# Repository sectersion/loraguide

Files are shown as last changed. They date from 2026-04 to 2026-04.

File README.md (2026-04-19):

# loraguide

Hello! In this guide, you will create a custom Meshtastic-enabled LORA board with a microcontroller, antenna, radio chip, and other things.

## First things first

To start your project, we need to download KiCad. KiCad is an open-source software for designing circuit boards, or PCBs. We can use the terms interchangably.

Go to https://www.kicad.org/download/ and install the version for your OS. After that finishes, create a new project. Name it anything you want, but I will name mine Loraguide.

After that finishes, you should be on a screen that looks like this: 



# The Schematic

The first step to designing a circuit board is the schematic. A schematic is essentially a wiring diagram, to show which components connect to what. That means it is very important that we follow a few design rules when creating our schematic:

 - Power symbols always point up
 - Ground symbols always point down
 - Net labels can be used instead of wires

First, click **Schematic Editor** on the main project page. Hit the **A** key to open the symbol chooser. Search "esp32-s3" and select the **ESP32-S3-WROOM-1**.



Place it in the middle. Next, search for the **SX1262** radio chip and place it to the left of the ESP32.

## Power system

### Organization
To keep things clean, use **Power Symbols** instead of drawing wires everywhere. Hit **P**, type +3V3, and place it on the 3V3 pin of the ESP32. Do the same for GND.

### Power input
Search for "USB_C_Receptacle_USB2.0_14P". 

Connect the GND pins to a GND power symbol. **Note on the SHIELD pins:** Do not connect these directly to GND. This can feed RF noise back into your host computer. For this project, leave the shield pins isolated or connected to a separate chassis pad if available.

Connect **VBUS** to a **+5V** power symbol. Place two **5.1k ohm** resistors (R_Small) on the **CC1** and **CC2** pins and connect the other ends to GND. This ensures your USB-C charger provides the correct 5V.



## SX1262 Power & RF

### Power Decoupling
Chips draw sudden bursts of current. Decoupling capacitors (100nF and 10µF) act as local water tanks, sitting right next to the chip to handle these bursts.

Connect **VDD_IN** to **+3V3** and place one **100nF** and one **10µF** capacitor between that line and GND.

### The DCC_SW Inductor
The SX1262 has an internal DC-DC converter that requires a **15µH inductor** on the **DCC_SW** pin. This inductor needs special care; it is a switching component right next to the radio. On the PCB, it must be placed as close as possible to the pin.

### RF Output Matching
Simply running a wire to the antenna is inefficient and can be illegal because it emits harmonics. You need a **matching network** (filtering) on the RF output. This usually involves a series inductor and capacitors to GND between the **RFO** pin and the antenna connector.

| Pin | What to do: |
|---|---|
| VDD_IN | Decouple with 100nF and 10µF |
| VBAT | Draw a direct wire to VDD_IN |
| VBAT_IO | Decouple with one 100nF capacitor |
| VREG | Decouple with one 100nF capacitor |
| DCC_SW | Connect 15µH inductor |
| VR_PA | 100nF capacitor to GND (DO NOT connect to 3.3V) |
| GND | Connect directly to GND |

### 5V to 3.3V conversion
Use an **AMS1117-3.3** LDO regulator to convert the 5V from USB to the 3.3V our chips need.

| Pin | Connection |
|-----|---|
| VIN | +5V from VBUS + 10µF cap to GND |
| VOUT | +3V3 + 10µF cap to GND |
| GND | GND |

## USB Data, Buttons, and SPI

### USB Data Lines
Connect the **D+** and **D-** pins of the USB connector to the **USB Data + and -** pins on the ESP32. Use **Net Labels (L)** to keep the wires from crossing.

### Boot and Reset Buttons
Both the **EN** (Reset) and **GPIO0** (Boot) pins need a **10kΩ pull-up resistor** to 3.3V. Connect push buttons that pull these pins to GND when pressed.

### SPI & Control Wiring
| Signal | ESP32 Pin | SX1262 Pin |
|---|---|---|
| SCK | GPIO5 | SCK |
| MOSI | GPIO6 | MOSI |
| MISO | GPIO7 | MISO |
| NSS | GPIO8 | NSS |
| RESET  | GPIO3 | RESET |
| BUSY | GPIO4 | BUSY |
| DIO1 | GPIO9 | DIO1 |

# PCB Section

## Footprint Assignment
In **Tools > Assign Footprints**, assign the physical shapes. For resistors and capacitors, **R_0402** or **C_0402** are standard for these boards.

## Placement
1. **ESP32:** Place at the top. Ensure the antenna "keep-out" area is outside the board edge.
2. **SX1262 & U.FL Connector:** Place these very close together.
3. **DCC_SW Inductor:** Place this right against the radio chip pin.
4. **Decoupling Caps:** Place them right next to their respective power pins.

## Routing Order
Sensitive signals must be routed first so they have the cleanest, most direct paths.

1. **RF Trace First:** Shortest path from chip to antenna. Use 45-degree angles.
2. **USB Data Lines:** Route D+ and D- as a pair, keeping them similar in length.
3. **SPI & Control Signals:** Connect the communication lines.
4. **Power Traces:** 3.3V and 5V. Use wider traces (0.5mm) for these.
5. **GND:** Handled by the copper pour.

## Ground Plane and Stitching
Add a **Filled Zone (Z)** for GND on both the top (**F.Cu**) and bottom (**B.Cu**) layers. 

To prevent "floating" ground islands and interference, add **stitching vias**. These are small holes that connect the top and bottom ground planes. Place them around the perimeter of the board and near the RF trace.

## Final Steps
Run the **DRC (Design Rule Check)** to find errors. Export your **Gerbers** and **Drill Files**, zip them up, and upload to a manufacturer like JLCPCB.

You have designed a grounded and RF-safe LoRa board.

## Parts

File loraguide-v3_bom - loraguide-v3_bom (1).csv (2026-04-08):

Designator | Footprint | Quantity | Value | LCSC Part #
C1, C3, C4, C5 | 402 | 4 | 100nF | C60474
C2, C6, C7 | 402 | 3 | 10uF | C315248
J1 | USB_C_Receptacle_GCT_USB4085 | 1 | USB_C_Receptacle_USB2.0_14P | C7095263
J2 | U.FL_Hirose_U.FL-R-SMT-1_Vertical | 1 | Conn_Coaxial | C434808
L1 | 603 | 1 | 15uH | C486329
R1, R2 | 402 | 2 | 5.1k | C105872
R3, R4 | 402 | 2 | 10k | C60490
SW1 | SW_SPST_B3U-1000P | 1 | RST | C231329
SW2 | SW_SPST_B3U-1000P | 1 | BOOT | C231329
U1 | ESP32-S3-WROOM-1 | 1 | ESP32-S3-WROOM-1 | C2913197
U2 | QFN-24-1EP_4x4mm_P0.5mm_EP2.6x2.6mm | 1 | SX1262IMLTRT | C191341
U3 | SOT-223-3_TabPin2 | 1 | AMS1117-3.3 | C6186
U4 | Bosch_LGA-8_2.5x2.5mm_P0.65mm_ClockwisePinNumbering | 1 | BME280 | C92489

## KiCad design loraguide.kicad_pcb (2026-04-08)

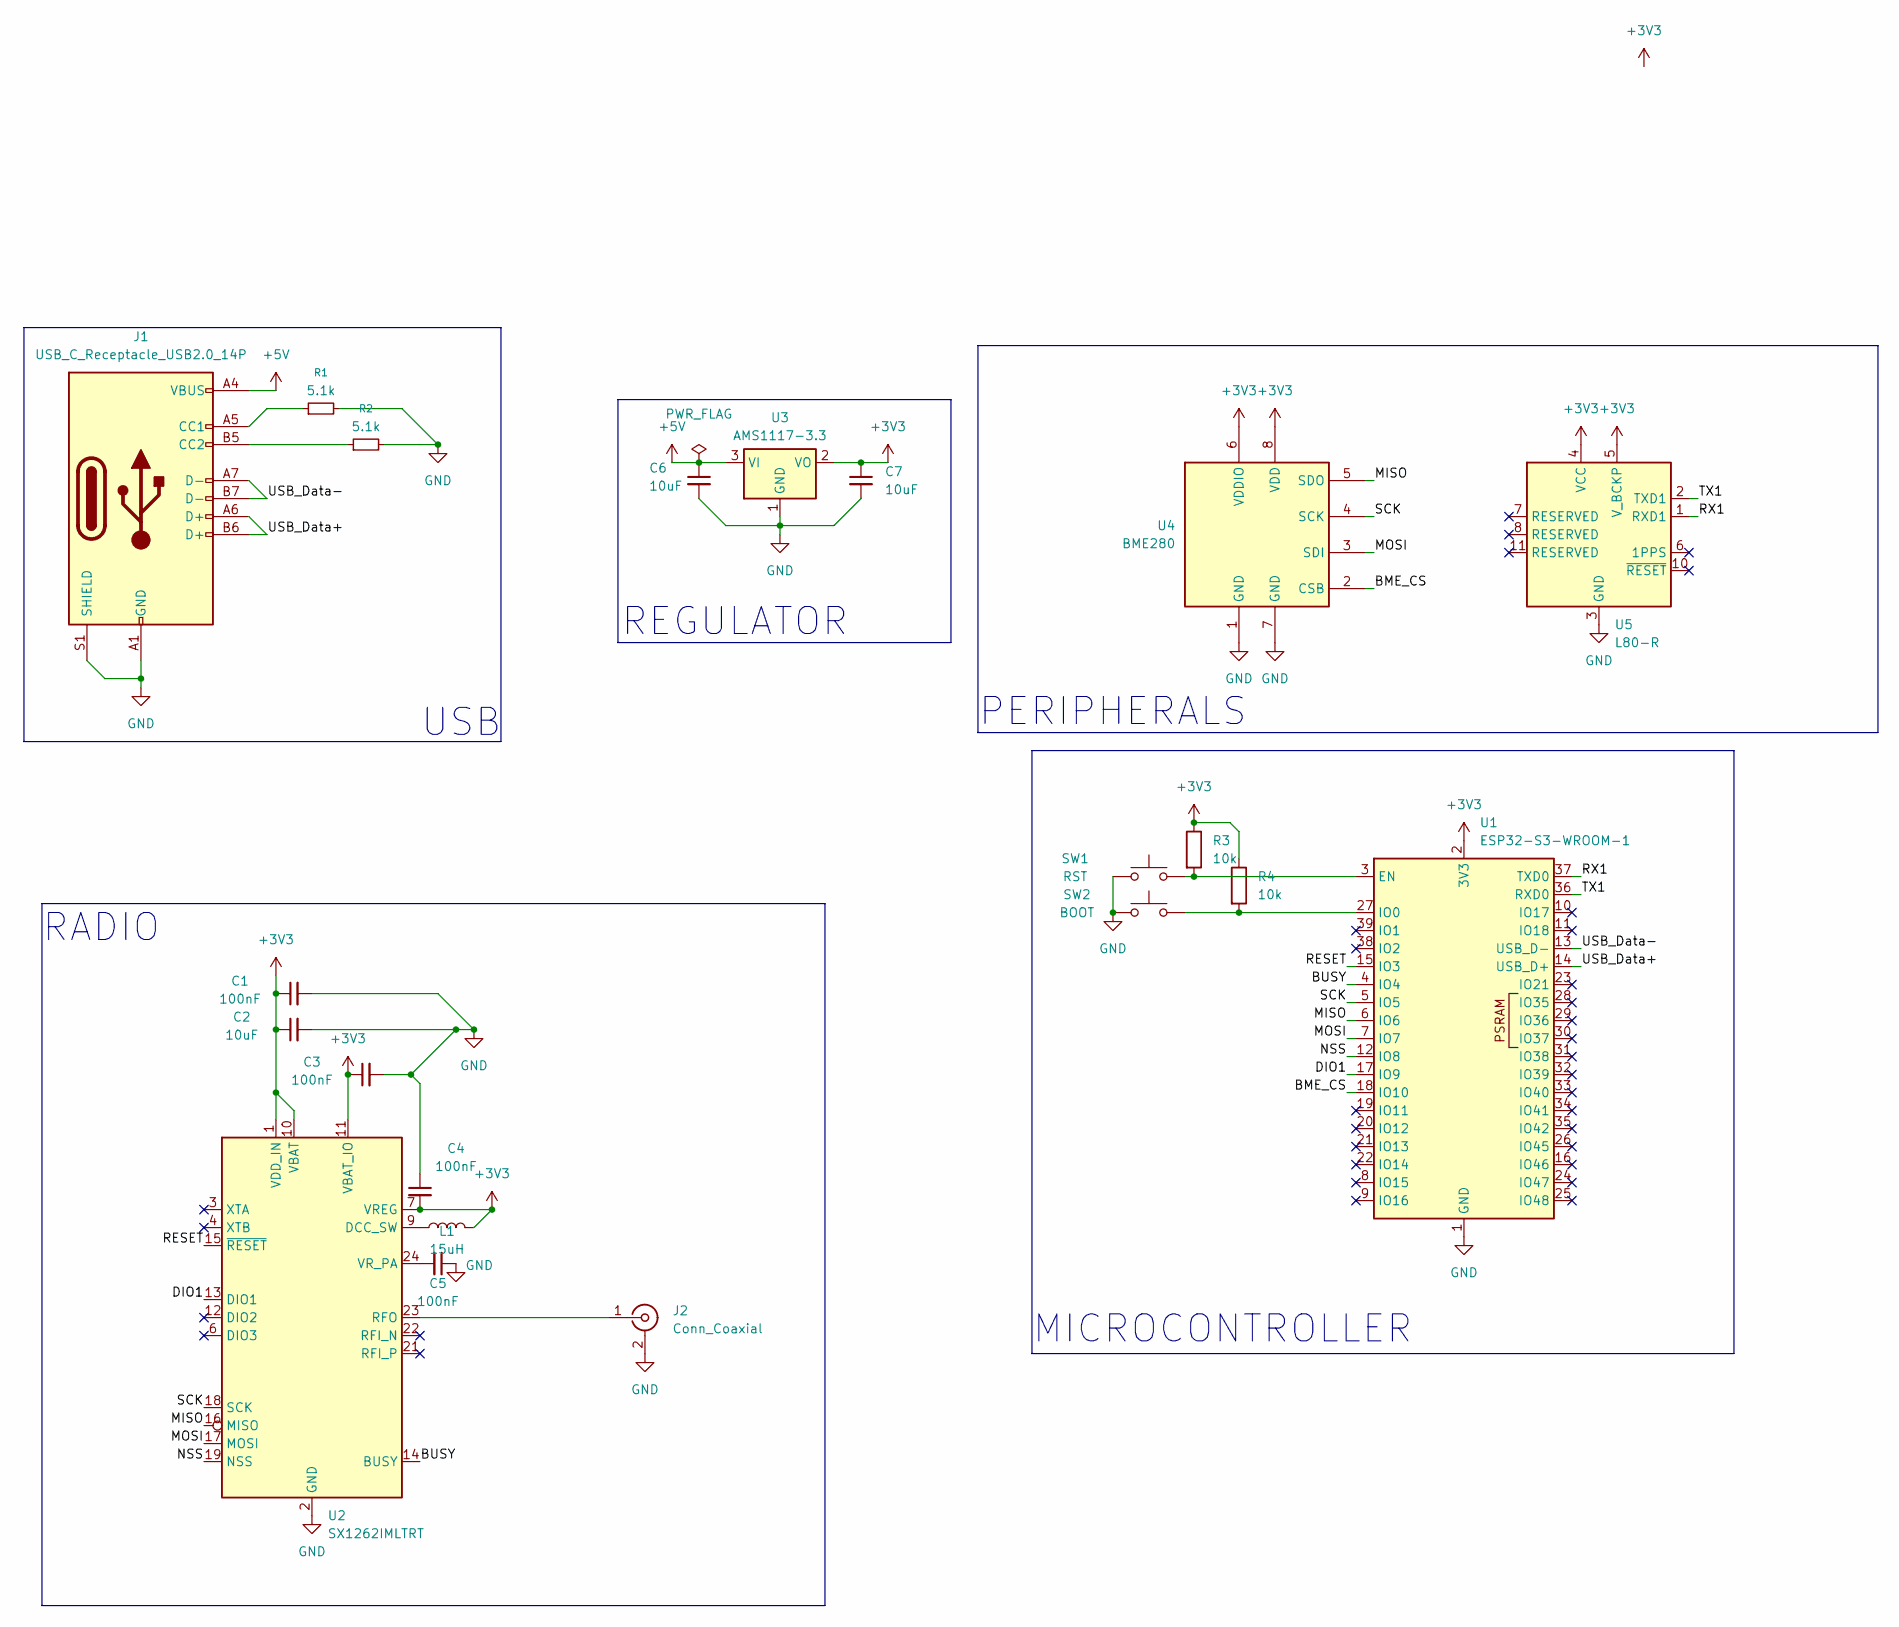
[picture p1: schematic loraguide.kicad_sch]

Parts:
C1, C3, C4, C5: 100nF; C_0402_1005Metric
C2, C6, C7: 10uF; C_0402_1005Metric
J1: USB_C_Receptacle_USB2.0_14P; USB_C_Receptacle_GCT_USB4085
J2: Conn_Coaxial; U.FL_Hirose_U.FL-R-SMT-1_Vertical
L1: 15uH; L_0603_1608Metric
R1, R2: 5.1k; R_0402_1005Metric
R3, R4: 10k; R_0402_1005Metric
SW1: RST; SW_SPST_B3U-1000P
SW2: BOOT; SW_SPST_B3U-1000P
U1: ESP32-S3-WROOM-1
U2: SX1262IMLTRT; QFN-24-1EP_4x4mm_P0.5mm_EP2.6x2.6mm
U3: AMS1117-3.3; SOT-223-3_TabPin2
U4: BME280; Bosch_LGA-8_2.5x2.5mm_P0.65mm_ClockwisePinNumbering
U5: L80-R; Quectel_L80-R

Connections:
+3V3: C1.1, C2.1, C3.1, C4.2, C7.1, L1.2, R3.1, R4.1, U1.2 (3V3), U2.1 (VDD_IN), U2.7 (VREG), U2.10 (VBAT), U2.11 (VBAT_IO), U3.2 (VO), U4.6 (VDDIO), U4.8 (VDD), U5.4 (VCC), U5.5 (V_BCKP)
+5V: C6.1, J1.A4 (VBUS), J1.A9 (VBUS), J1.B4 (VBUS), J1.B9 (VBUS), U3.3 (VI)
/BME_CS: U1.18 (IO10), U4.2 (CSB)
/BUSY: U1.4 (IO4), U2.14 (BUSY)
/DIO1: U1.17 (IO9), U2.13 (DIO1)
/MISO: U1.6 (IO6), U2.16 (MISO), U4.5 (SDO)
/MOSI: U1.7 (IO7), U2.17 (MOSI), U4.3 (SDI)
/NSS: U1.12 (IO8), U2.19 (NSS)
/RESET: U1.15 (IO3), U2.15 (~RESET)
/RX1: U1.37 (TXD0), U5.1 (RXD1)
/SCK: U1.5 (IO5), U2.18 (SCK), U4.4 (SCK)
/TX1: U1.36 (RXD0), U5.2 (TXD1)
/USB_Data+: J1.A6 (D+), J1.B6 (D+), U1.14 (USB_D+)
/USB_Data-: J1.A7 (D-), J1.B7 (D-), U1.13 (USB_D-)
GND: C1.2, C2.2, C3.2, C4.1, C5.1, C6.2, C7.2, J1.A1 (GND), J1.A12 (GND), J1.B1 (GND), J1.B12 (GND), J1.S1 (SHIELD), J2.2 (Ext), R1.2, R2.2, SW1.1, SW2.1, U1.1 (GND), U1.40 (GND), U1.41 (GND), U2.2 (GND), U2.5 (GND), U2.8 (GND), U2.20 (GND), U2.25 (GND), U3.1 (GND), U4.1 (GND), U4.7 (GND), U5.3 (GND), U5.12 (GND)
unnamed: J1.A5 (CC1), R1.1
unnamed: J1.B5 (CC2), R2.1
unnamed: J2.1 (In), U2.23 (RFO)
unnamed: R3.2, SW1.2, U1.3 (EN)
unnamed: R4.2, SW2.2, U1.27 (IO0)
unnamed: L1.1, U2.9 (DCC_SW)
unnamed: C5.2, U2.24 (VR_PA)

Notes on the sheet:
RADIO
PERIPHERALS
REGULATOR
USB
MICROCONTROLLER

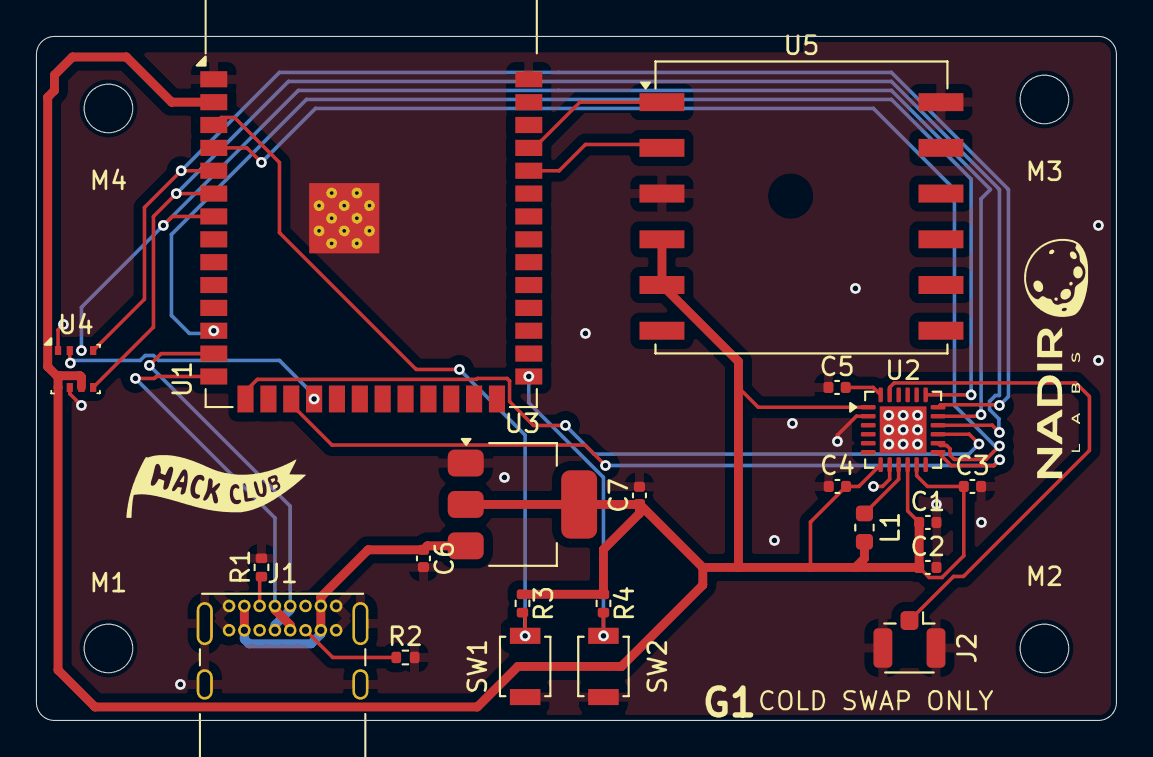
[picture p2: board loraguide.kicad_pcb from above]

Board: 2 copper layers, 60.0 x 38.0 mm, 27 parts (0 on the bottom side), 22 nets.

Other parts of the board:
G1: LOGO; nl_bw_large
G2: LOGO; hc_bw_small
M1, M2, M3, M4: MountingHole_2.7mm_M2.5

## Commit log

2026-03-21 Expand README with KiCad setup and schematic guidance
    Added detailed instructions for setting up KiCad and creating a schematic for the LORA board project, including design rules and component placement.
2026-03-22 finish schematic
    [loraguide.kicad_pcb, loraguide.kicad_sch]
2026-03-22 finish schematic section
    Updated the README to include detailed instructions on circuit board design, power input, and component connections for the ESP32 and SX1262.
2026-03-22 finished pcb upload + gerbers
    [loraguide.kicad_pcb, loraguide.kicad_sch]
2026-03-22 upload step
    [v1_bom.csv]
